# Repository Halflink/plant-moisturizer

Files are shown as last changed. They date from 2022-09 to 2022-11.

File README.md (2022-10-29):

# Plant Moisturizer project

## PROJECT
| Project name: | Halflink/plant-moisturizer |
|---|---|
| Author: | Jeroen van Zwam |
| Date: | 2021-10-25 |  
| Last update: | 2022-09-28 |
| Project type: | Raspberry Pi |

## Executable
* Start main.py 

## PROJECT DESCRIPTION
This project started with the plants on my balcony needing water every day.
Although the plants are all low- maintenance plants, the location and type of the balcony means they get dry very quick.
To solve this I picked up the idea to create an automated watering system.

### Scope
* Measure moisture levels of plants
* Regular moisturizing of plants
* Check water level in water container
* Air temperature check 
* Browser based interface showing all parameters
* RGB Led: 
  * Green: application has started
  * Blue: application is shutting down
  * Red: application is in error
* Shutdown button: starts closing of application and sends shutdown command to OS

### Pi 4 Model B choice
The Pi 3 Model B is still available and might be a cheaper choice. The reason I opted for the Pi4B is that this Pi 
should be able to handle more ampere, and as I plan to use 4-5 sensors, a web service and a relay hat I might need 
that extras.

### DC-DC step-down converter
The pumps need roughly 12 volts to operate properly (I plan to water a lot of plants). The Pi & sensors need a stable 5 volts. 
For this I plan to use a DC-DC step-down converter to create a stable 5 volt for the Pi. 
 
## PI INSTALLATION NOTES
* Connect remotely so we can use the raspberry headless
  * Set up SSH 
  * Set up WIFI
  * Install GIT `sudo apt-get install git`
* I2C for relay HAT:
  * Set up [I2C](https://wiki.52pi.com/index.php?title=DockerPi_4_Channel_Relay_SKU:_EP-0099)
  * Install smbus package for python `sudo apt-get install python3-smbus`
* Use init.json to set up the HAT, GPIO ports etc.
* Set up MCP3008 [MCP3008](https://learn.adafruit.com/raspberry-pi-analog-to-digital-converters/mcp3008)
* Install FLASK `sudo apt-get install python3-flask`
* Set up DHT22 sensor: https://pimylifeup.com/raspberry-pi-humidity-sensor-dht22/
  * `sudo pip3 install Adafruit_DHT`  

## PARTS LIST*
* 1x Raspberry Pi 4 Model B 2GB RAM
* 1x [MCP3008](https://elektronicavoorjou.nl/product/mcp3008/)
* 1x [Step-down DC-DC Power Converter](https://www.robotshop.com/eu/en/step-down-dc-dc-power-converter-25w.html)
* 1x [4-channel relay hat](https://www.robotshop.com/eu/en/4-channel-relay-hat-raspberry-pi-3b-3b2b.html)
* 1x [Temperature & humidity sensor](https://www.robotshop.com/eu/en/dht22-temperature-humidity-sensor.html)
* 3x [Immersible water pump](https://www.robotshop.com/eu/en/immersible-water-pump-water-tube.html)
* 4x [DFRobot moisture sensor](https://www.robotshop.com/eu/en/dfrobot-moisture-sensor.html)
* Water reservoir (not yet bought)
* watering tubes (not yet bought)
* Housing for raspberry pi & components (not yet bought)
* 4x 1M&#937; resistors
* 1x 10K&#937; resistor
* 3x 220&#937; resistors
* 1x RGB led (common anode)
* 1x button

*) Please note that only the major parts are mentioned

## TO DO LIST
* ~~Program relay hat handler~~ 
* ~~Program MCP3008 handler~~
* ~~Program logging~~
* Program web interface
  * ~~Create moisture chart~~
  * ~~Create buttons to activate pumps~~
  * ~~read-out sensors in seperate thread~~
  * ~~Create humidity chart~~
  * ~~Create current temperature gauge~~
* ~~Set-up autostart when booting~~ -> done using a launcher script started by crontab
* Create enclosure for all the parts
* Create PCB for all electronic parts
* ~~Set up power converter~~
* Create tubing system and sprinklers
* Create water reservoir
* Find solution for SD card corruption (planning to have a high up-time)

## Progress
### Added relay hat and MCP3008 chip on breadboard
Breadboard Added MCP3008
### moved test set-up to my new test bench
Test bench Moved to test box
### Test set-up at Spark Makers Zone
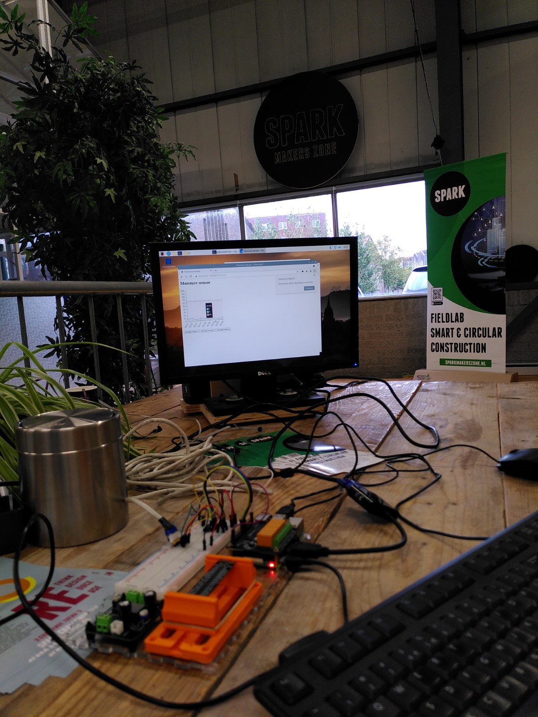
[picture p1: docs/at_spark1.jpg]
Spark At Spark Makers Zone

### Test set-up having connected all sensors
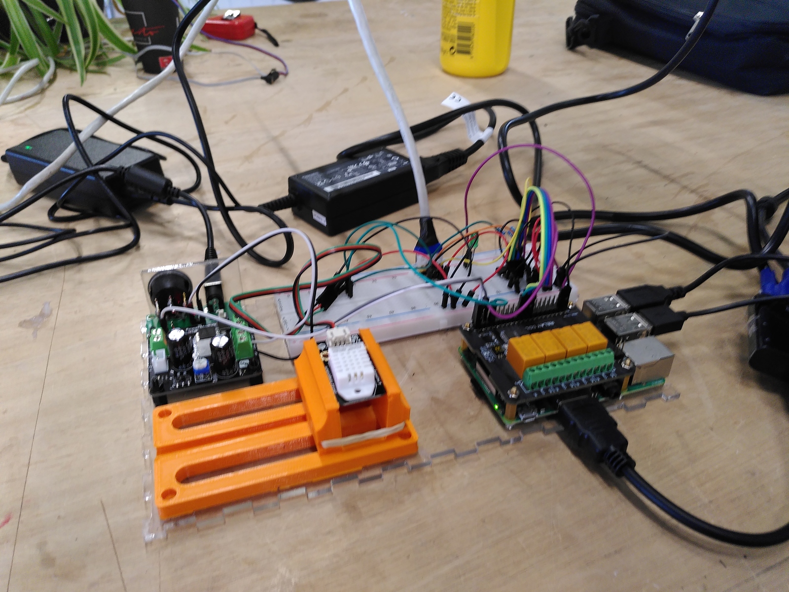
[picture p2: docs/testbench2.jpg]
Test bench Sensors are complete

### PCB design
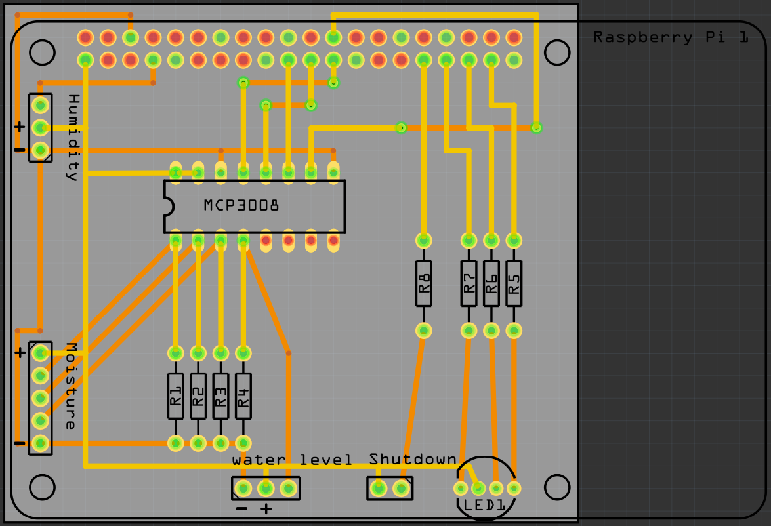
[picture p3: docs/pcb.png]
PCB PCB design

### Screenprint webinterface
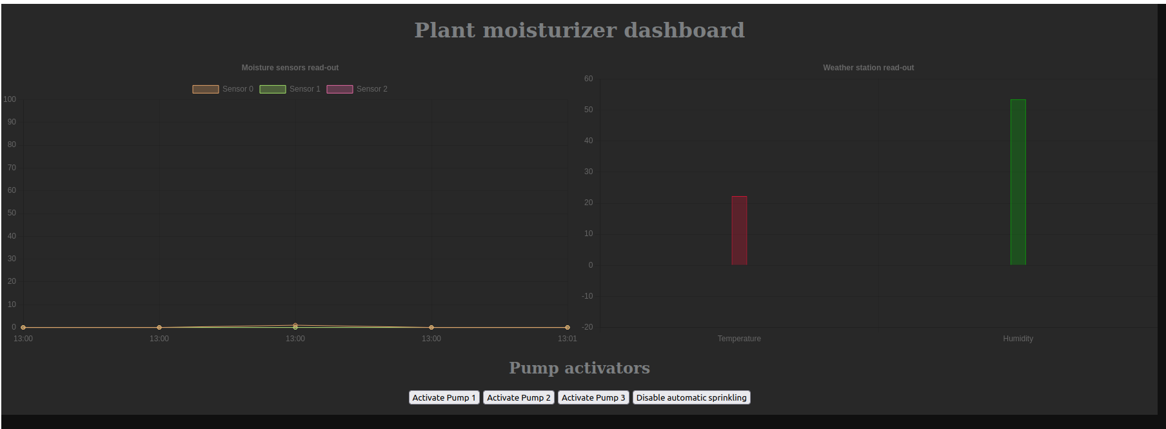
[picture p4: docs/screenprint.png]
Interface Interface example


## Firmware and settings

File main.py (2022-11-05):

import time


class MainClass:
    # Import
    import sys
    from HumiditySensor import HumiditySensor
    from JsonHandler import JsonHandler
    from RelayHat import RelayHat
    from MoistureSensor import MoistureSensor
    from Logger import Logger
    import logging
    import threading
    import time as time
    import datetime as datetime
    import RPi.GPIO as GPIO

    # Variables
    stop_thread_event = threading.Event()
    auto_sprinkling = False

    class PowerLed:

        def __init__(self, GPIO, led_gpio):
            self.GPIO = GPIO
            self.red_gpio = led_gpio[0]
            self.green_gpio = led_gpio[1]
            self.blue_gpio = led_gpio[2]
            self.GPIO.setmode(GPIO.BCM)
            self.GPIO.setup(self.red_gpio, self.GPIO.OUT)
            self.GPIO.setup(self.green_gpio, self.GPIO.OUT)
            self.GPIO.setup(self.blue_gpio, self.GPIO.OUT)

        def led_off(self):
            rgb = [False, False, False]
            self.led_set(rgb)

        def led_set(self, rgb):
            if rgb is not None:
                if rgb[0]:
                    self.GPIO.output(self.red_gpio, self.GPIO.LOW)
                else:
                    self.GPIO.output(self.red_gpio, self.GPIO.HIGH)

                if rgb[1]:
                    self.GPIO.output(self.green_gpio, self.GPIO.LOW)
                else:
                    self.GPIO.output(self.green_gpio, self.GPIO.HIGH)

                if rgb[2]:
                    self.GPIO.output(self.blue_gpio, self.GPIO.LOW)
                else:
                    self.GPIO.output(self.blue_gpio, self.GPIO.HIGH)

        def led_on(self, colour):
            rgb = None
            if colour == 'RED':
                rgb = [True, False, False]
            elif colour == 'GREEN':
                rgb = [False, True, False]
            elif colour == 'BLUE':
                rgb = [False, False, True]
            elif colour == 'CYAN':
                rgb = [False, True, True]
            elif colour == 'MAGNENTA':
                rgb = [True, False, True]
            elif colour == 'YELLOW':
                rgb = [True, True, False]
            else:
                rgb = [False, False, False]
            self.led_set(rgb)

    def __init__(self):

        # Get settings
        json_handler = self.JsonHandler()

        # Set power LED
        self.powerLed = self.PowerLed(self.GPIO, json_handler.rgb_led_gpio)

        # Initialize logging. The logger class is only there to initialize pythons logging module
        self.log_name = 'MoisturizerLogging'
        self.logger = self.Logger(log_level=json_handler.log_level,
                                  log_name=self.log_name,
                                  log_folder=json_handler.log_path)
        self.log = self.logging.getLogger(self.log_name)

        # Set pumps (relais hat)
        self.relayHat = self.RelayHat(device_addr=json_handler.device_addr,
                                      device_bus=json_handler.device_bus,
                                      pump_settings=json_handler.pump_settings,
                                      log_name=self.log_name)

        # Set Sensors in own thread
        self.moistureSensors = self.MoistureSensor(log_name=self.log_name, bus=json_handler.spi_bus,
                                                   device=json_handler.spi_device,
                                                   readout_history_length=json_handler.spi_readout_history_length)
        self.humiditySensor = self.HumiditySensor(log_name=self.log_name, dht_pin=json_handler.humidity_sensor_gpio)
        self.sensor_thread = self.threading.Thread(target=self.sensor_thread_function, args=("sensor thread",
                                                                                             self.stop_thread_event))
        self.readout_interval = json_handler.spi_readout_interval

        # Set web port number
        self.web_port_number = json_handler.web_port_number

    def power_led_program_running(self):
        self.powerLed.led_on("GREEN")

    def deactivate_power_led(self):
        self.powerLed.led_off()

    def cleanup_gpio(self):
        self.GPIO.cleanup()

    def activate_pump(self, pump_index):
        if 0 <= pump_index < self.relayHat.length():
            self.relayHat.water_plants(pump_index)

    def check_time_difference(self, time_stamp_1, time_stamp_2, interval):
        if time_stamp_1 is None or time_stamp_2 is None:
            return True
        else:
            time_stamp = time_stamp_1 + self.datetime.timedelta(seconds=interval)
            return time_stamp < time_stamp_2

    def check_sprinkler(self):
        for pump in self.relayHat.pumps:
            readout_sensor = self.moistureSensors.get_last_readout(pump.sensor)
            pump_sensor_threshold = pump.sensor_threshold
            self.log.debug('check_sprinkler: Iterating pumps: pump {} , readout is {}, threshold is {}'.format(
                pump.pump_id, readout_sensor, pump_sensor_threshold))
            if readout_sensor <= pump_sensor_threshold:
                if self.check_time_difference(pump.last_run_datetime, self.datetime.datetime.now(),
                                              pump.sprinkler_interval):
                    pump.water_plants()

    def pump_test(self):
        while True:
            try:
                for i in range(self.relayHat.length()):
                    self.log.info('Pump = %.1f ' % i)
                    self.relayHat.water_plants(i)
                    print(self.moistureSensors.get_last_read_out_string())
            except KeyboardInterrupt as e:
                print('Quit the Loop')
                self.sys.exit()

    def sensor_thread_function(self, thread_name, stop_thread_event, ):
        self.log.debug('Initializing ' + thread_name)
        last_readout_datetime = None
        try:
            while True:
                current_datetime = self.datetime.datetime.now()
                if self.check_time_difference(last_readout_datetime, current_datetime,
                                              self.readout_interval):
                    last_readout_datetime = current_datetime
                    self.moistureSensors.write_sensor_read_out()
                    self.humiditySensor.write_sensor_read_out()
                if self.auto_sprinkling:
                    self.check_sprinkler()
                if stop_thread_event.is_set():
                    self.log.debug('sensor_thread_function: Sensor thread is stopped')
                    break
        except KeyboardInterrupt as e:
            self.log.info('Sensor thread keyboard interruption')
            self.moistureSensors.close()
        except Exception as e:
            self.powerLed.led_set("RED")
            self.log.exception("Error occurred in sensor thread")
            self.log.exception(e)

    def start_sensor_thread(self):
        self.sensor_thread.start()

    def end_sensor_thread(self):
        self.powerLed.led_on('BLUE')
        self.stop_thread_event.set()
        print('Wait for tread to stop...')
        self.sensor_thread.join()


if __name__ == '__main__':
    # If main is started, it will test the sensors and the pumps.
    mainClass = MainClass()
    mainClass.start_sensor_thread()
    mainClass.pump_test()

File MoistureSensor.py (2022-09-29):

class MoistureSensor:
    """
        Class for MCP3008 ADC
        Using the MCP3008 chip to read out the sensors.

        sensor_data_matrix:
            x: sensor_no (sensor 0, sensor 1, sensor 2)
            y: reading_no (reading 0, reading 1,.... reading 9)
    """
    from spidev import SpiDev
    import logging
    import datetime

    # Variables
    sensor_data_matrix = []
    sensor_data_times = []

    def __init__(self, log_name='', bus=0, device=0, readout_history_length=10):
        self.bus, self.device, self.readout_history_length = bus, device, readout_history_length
        self.spi = self.SpiDev()
        self.open()
        self.spi.max_speed_hz = 1000000  # 1MHz
        self.log = self.logging.getLogger(log_name)

    def add_sensor_data(self, sensor_data):
        # record read out and time of read out
        self.sensor_data_matrix.append(sensor_data)
        if len(self.sensor_data_matrix) > self.readout_history_length:
            self.sensor_data_matrix.pop(0)  # keep only 10 readouts in the array
        now = self.datetime.datetime.now()
        self.sensor_data_times.append(now.strftime("%H:%M"))
        if len(self.sensor_data_times) > self.readout_history_length:
            self.sensor_data_times.pop(0)  # keep only 10 readouts in the array

    def close(self):
        self.spi.close()

    @staticmethod
    def convert_list_to_string(read_out):
        """
        get a float-list and return it as a string separated by piping
        :param read_out: list with floats
        :return: floats rounded on 2 concatenated with piping
        """
        read_out_string = ''
        for i in range(len(read_out)):
            if read_out_string != '':
                read_out_string = read_out_string + ' | '
            read_out_string = read_out_string + str(read_out[i])
        return read_out_string

    def get_last_read_out_string(self):
        return self.convert_list_to_string(self.sensor_data_matrix[-1])

    def get_last_readout(self, sensor):
        return self.sensor_data_matrix[-1][sensor]

    def get_sensor_data(self, sensor_no):
        values = []
        for i in range(len(self.sensor_data_matrix)):
            sensor_data = self.sensor_data_matrix[i]
            values.append(round(sensor_data[sensor_no], 2))
        return values

    def get_sensor_data_times(self):
        values = []
        for i in range(len(self.sensor_data_times)):
            time_stamp = self.sensor_data_times[i]
            values.append(time_stamp)
        return values

    def open(self):
        # connect spi object to spi device
        self.spi.open(self.bus, self.device)
        self.spi.max_speed_hz = 1000000  # 1MHz

    def read_sensor(self, channel=0):
        """
        read SPI data from MCP3008 on channel -> digital value
            spi.xfer2() send three bytes to the device
                the first byte is 1 -> 00000001
                the second byte is 8 + channel and left shift with 4 bits
                the third byte is 0 -> 00000000
            the device return 3 bytes as response
        """

        # perform spi transaction
        adc = self.spi.xfer2([1, (8 + channel) << 4, 0])
        # extract value from data bytes
        data = ((adc[1] & 3) << 8) + adc[2]

        # max value is 100. So divide by 10 and round
        value = round(data/10, 0)
        return value

    def write_sensor_read_out(self):
        """
        Read out all sensors and write them to file
        Also keep last 10 readouts in variable
        """
        read_out = [self.read_sensor(channel=0), self.read_sensor(channel=1), self.read_sensor(channel=2)]
        self.log.info('Moisture read-out: ' + self.convert_list_to_string(read_out))
        self.add_sensor_data(read_out)


if __name__ == '__main__':
    # run this class stand alone o test class
    import sys
    import time
    from Logger import Logger

    logger = Logger(log_level=10, log_name='test sensor')
    moistureSensor = MoistureSensor(log_name='test sensor')
    while True:
        try:
            moistureSensor.write_sensor_read_out()
            print(moistureSensor.get_last_read_out_string())
            time.sleep(1)
        except KeyboardInterrupt as e:
            print("Quit the Loop")
            sys.exit()

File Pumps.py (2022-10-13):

import logging


class Pumps:
    import smbus
    import logging

    class Pump:

        # Import
        import time as time
        from datetime import datetime as datetime
        import logging

        last_run_datetime = None

        def __init__(self, bus, pump_id, pump_time, device_addr, log_name, sprinkler_interval, sensor
                     , sensor_threshold):

            self.log = self.logging.getLogger(log_name)
            self.device_addr = device_addr
            self.pump_id = pump_id
            self.pump_time = pump_time
            self.bus = bus
            self.sprinkler_interval = sprinkler_interval
            self.sensor = sensor
            self.sensor_threshold = sensor_threshold

        def start_pump(self):
            self.log.info('Start pump %.1f ' % self.pump_id)
            self.bus.write_byte_data(self.device_addr, self.pump_id, 0xFF)

        def stop_pump(self):
            self.log.debug('Stop pump %.1f ' % self.pump_id)
            self.bus.write_byte_data(self.device_addr, self.pump_id, 0x00)

        def water_plants(self):
            if self.last_run_datetime is not None:
                last_run = self.last_run_datetime.strftime("%d-%m-%Y, %H:%M:%S")
                self.log.info('water_plants: Last run pump {} is at {}'.format(self.pump_id, last_run))
            else:
                self.log.info('water_plants: first time running pump {}'.format(self.pump_id))
            self.start_pump()
            self.time.sleep(self.pump_time)
            self.stop_pump()
            self.last_run_datetime = self.datetime.now()

    def __init__(self, device_addr, device_bus, pump_settings, log_name):

        self.log = self.logging.getLogger(log_name)
        self.bus = self.smbus.SMBus(device_bus)
        self.pumps = []

        no_of_pumps = len(pump_settings)
        for element in range(no_of_pumps):
            self.log.debug('Pump ID: %.1f ' % pump_settings[element]['ID'])
            self.log.debug('Pump time: %.1f ' % pump_settings[element]['Pump time'])
            pump = self.Pump(bus=self.bus,
                             pump_id=pump_settings[element]['ID'],
                             pump_time=pump_settings[element]['Pump time'],
                             device_addr=device_addr,
                             log_name=log_name,
                             sprinkler_interval=pump_settings[element]['Sprinkler interval'],
                             sensor=pump_settings[element]['Sensor'],
                             sensor_threshold=pump_settings[element]['Sensor threshold'])
            self.pumps.append(pump)

    def length(self):
        length = len(self.pumps)
        return length

    def get_pump(self, pump_no):
        pump = self.pumps[pump_no]
        return pump

    def water_plants(self, pump_no):
        pump = self.get_pump(pump_no)
        if pump is not None:
            pump.water_plants()

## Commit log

2021-10-27 Added Relay hat logic & JSON intitiation file. To do: Create pump class with pump method
2021-11-06 Created pumps class with watereing_plants method Also, you can add 1-4 pumps in the init file depending how much and with what ID yyou create the pumps in the init file the corresponding relays are u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
2022-06-15 added try-out for chart, and prepared sensor class wor getting multiple output
2022-06-19 adding logging to sensor read-outs. Also adding method to store 10 last readouts
2022-06-25 Adding thread to read out sensors
2022-09-20 Revert "adding timestamp to readouts"
    This reverts commit cb61ac2e5c30470d0c59d6eeae20d3ae8c85797b.
    [WebInterface.py]
2022-09-20 Revert "adding timestamp to readouts"
    This reverts commit 9831bd774571addbb8abbaa6287ed668de58eb62.
    [WebInterface.py]
2022-09-28 adding timestamp to readouts
    [PCB_header.fzz]
2022-09-29 jeroen@svobo.nl Add "auto" button -> automatic sprinkling
    [PCB_header.fzz]
2022-10-29 jeroen@svobo.nl Add RGB led
    [PCB_header.fzz]
